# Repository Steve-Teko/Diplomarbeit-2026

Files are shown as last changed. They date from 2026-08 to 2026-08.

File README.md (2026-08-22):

# Diplomarbeit-2026
Offizielle Repository fuer die Diplomarbeit von Steve

**Idee:**
Die Idee ist es Leiterplatten zu designen, die in einem neuen oder bestehenden SmartHome mit einfachen Schritten integrierbar sind.
Es sollen einfache aber Funktionsreiche Leiterplatten die z.B. im Fall des Aktor Prints, per I2C an bereits vorhandene Steuerungen verwendet werden koennen.

**Meine Qualifikationen:**
Gelernt habe ich Automatiker und interessiere mich seit meiner Kindheit fuer viele Technik relevante Themen. Schulisch war ich schon immer einer dem die Themen Kunst und Sprachen weniger interessierten im vergleich zu Mathe, Physik und Handarbeit.
Mit 23 hatte ich eine Entscheidung getroffen, mich Schulisch weiterzubilden. Dies ist bis jetzt immer noch eine Entscheidung die ich nicht bereue. Der Weg bis zu dieser Arbeit war steinig und hart.
Leiterplatten hatte ich einmal in der Lehre mit meinem damaligen Lehrlingsbetreuer gezeichnet, dies aber danach nie mehr ausgefuehrt. Damals hatten wir Eagle als Programm.

**Die Umsetzung:**
Zu diesem Repo existiert noch meine Arbeit die ich Paralell dazu Schreibe. Die Idee des Repo ist es die notwendigen Daten: KiCad, Gerber Files, Gehause oder Programmzeilen fuer spaetere vorhaben zu Speichern.
Die Arbeit werde ich nicht auf das Repo hochladen.

**Haftungsausschluss:**
Ich bin weder fuer die korrekte Anwendung noch meine Fehler Verantwortlich, saemtliche Schaeden die durch alle Dateien auf diesem Repo verursacht wurden, sind alleinig dem Anwender zuzuschreiben.
Die Leiterplatten sind von keinem Pruefunternehmen abgenommen oder auf ihre Sicherheit geprueft worden. Bei Verwendung sind alle Regeln der Technik zu beachten.

#################################################################################################

Official repository for Steve's diploma thesis.

**Idea**
The concept is to design printed circuit boards (PCBs) that can be easily integrated into a new or existing smart home system.
The goal is to create simple yet feature-rich PCBs—such as the actuator board—that can connect to existing control systems via I2C.

**My Qualifications**
I am a trained automation technician (Automatiker) and have been interested in various tech-related topics since childhood. At school, I was always far less interested in art and languages compared to math, physics, and practical crafts.
At age 23, I decided to further my education—a choice I still do not regret. The path leading up to this project has been tough and challenging.
I had designed PCBs once during my apprenticeship alongside my mentor using EAGLE, but I never worked with PCB design again after that.

**Implementation**
In addition to this repository, I am writing my written thesis in parallel. The purpose of this repo is to store the necessary project files—such as KiCad files, Gerber files, enclosure models, or code lines—for future reference.
I will not be uploading the written thesis itself to this repository.

**Disclaimer**
I am responsible neither for the correct application of these files nor for any errors within them. Any damages caused by files in this repository are solely the responsibility of the user.
The PCBs have not been certified or safety-tested by any official inspection body. When using them, all applicable engineering standards and safety codes must be strictly followed.

**What to expect:**
You will be able to order a the Following PCB from your favorite PCB Manufacturer, the Files and a basic Enclosure designed in FreeCAD is included in the Folders

**Hauptprint aka the Brain**
It's purpose is being able to be integrated in to your existing SmartHome while offering a wide range off preconfigured In/Output.
The ESP32 C6 Wroom1 supports Thread/Zigbee, Wi-Fi 6 (2.4gHz only!), Bluetooth 5.0, UART, I2C and I2S.

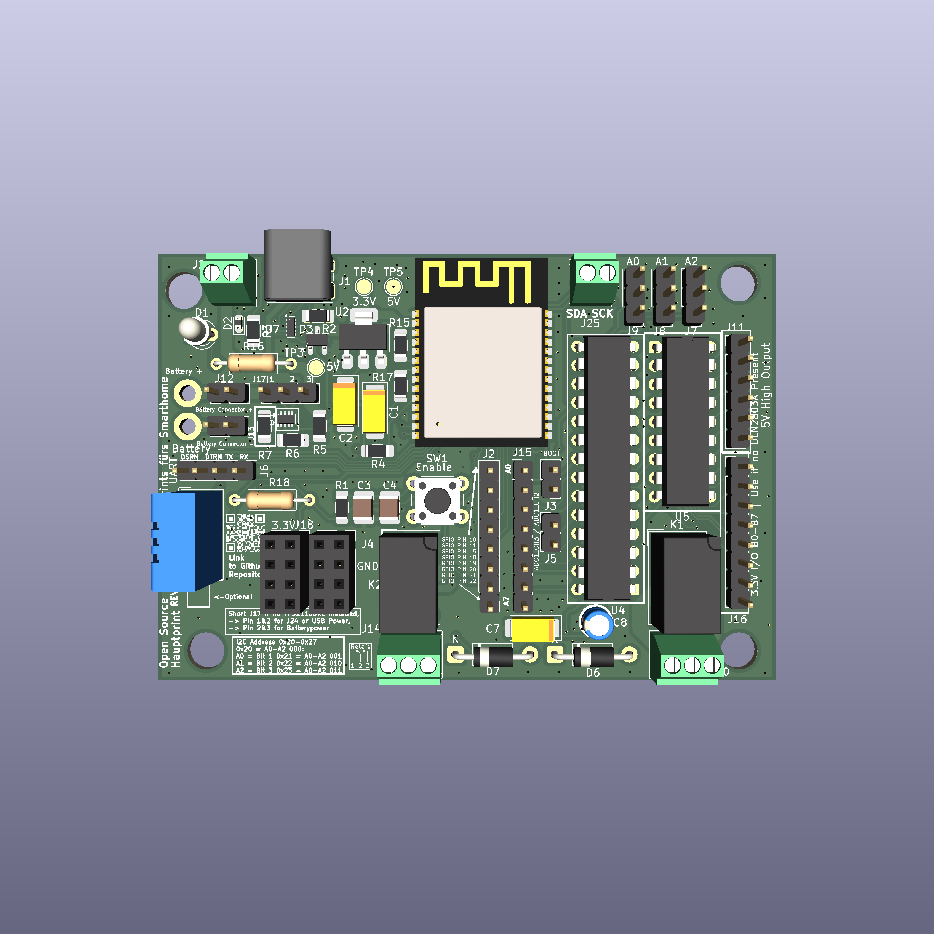
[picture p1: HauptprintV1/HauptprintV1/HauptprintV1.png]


**The RelaisExpanderPrint aka the Switchmaster**
The RelaisExpanderPrint was designed with compatibility and versatility in mind. The Idea was to create a 16x Relays Switching device with Potential-free contacts in mind, as you would find on a PLC or in an Switching Cabinet.
Its size is as compact as i was able to design it with an Power-supply input that support different Voltage Levels depending on your needs.
The TracoPower Component (PS1) is interchangeable in its product line so you can choose Supply Voltages ranging from 9V,12V,24V or up to 75V DC. 

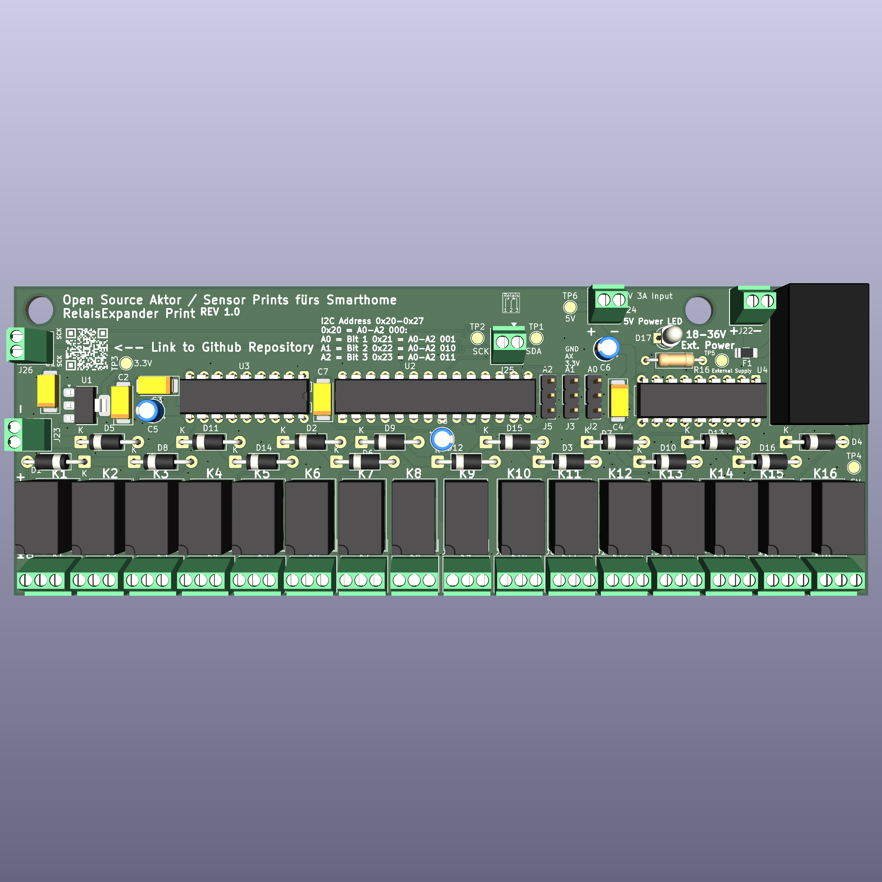
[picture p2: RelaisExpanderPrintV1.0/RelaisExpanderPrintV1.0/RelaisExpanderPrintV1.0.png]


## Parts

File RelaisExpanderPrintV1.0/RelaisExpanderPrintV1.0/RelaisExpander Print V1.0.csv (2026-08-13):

# | Reference | Qty | Value | Footprint | DNP
1 | C1, C5, C6, C8 | 4 | 10uF | Capacitor_Tantalum_SMD:CP_EIA-6032-20_AVX-F_HandSolder
2 | C2 | 1 | 22uF | Capacitor_Tantalum_SMD:CP_EIA-6032-20_AVX-F_HandSolder
3 | C3, C4, C7 | 3 | 100nF | Capacitor_Tantalum_SMD:CP_EIA-6032-20_AVX-F_HandSolder
4 | D1, D2, D3, D4, D5, D6, D7, D8, D9, D10, D11, D12, D13, D14, D15, D16 | 16 | 1N4007 | Diode_THT:D_DO-41_SOD81_P10.16mm_Horizontal
5 | D17 | 1 | LED | LED_THT:LED_D3.0mm_Clear
6 | F1 | 1 | Fuse | Fuse:Fuse_1206_3216Metric
7 | J2 | 1 | A0 | Connector_PinHeader_2.54mm:PinHeader_1x03_P2.54mm_Vertical
8 | J3 | 1 | A1 | Connector_PinHeader_2.54mm:PinHeader_1x03_P2.54mm_Vertical
9 | J4 | 1 | I2C | Connector_PinHeader_2.54mm:PinHeader_1x02_P2.54mm_Vertical
10 | J5 | 1 | A2 | Connector_PinHeader_2.54mm:PinHeader_1x03_P2.54mm_Vertical
11 | J6, J7, J8, J9, J10, J11, J12, J13, J14, J15, J16, J17, J18, J19, J20, J21 | 16 | Screw_Terminal_01x03 | TerminalBlock_Phoenix:TerminalBlock_Phoenix_MPT-0,5-3-2.54_1x03_P2.54mm_Horizontal
12 | J22 | 1 | 18-36V External Powersupply | TerminalBlock_Phoenix:TerminalBlock_Phoenix_MPT-0,5-2-2.54_1x02_P2.54mm_Horizontal
13 | J23 | 1 | 5V Out | TerminalBlock_Phoenix:TerminalBlock_Phoenix_MPT-0,5-2-2.54_1x02_P2.54mm_Horizontal
14 | K1, K2, K3, K4, K5, K6, K7, K8, K9, K10, K11, K12, K13, K14, K15, K16 | 16 | G5LE-1 | Relay_THT:Relay_SPDT_Omron_G5V-1
15 | PS1 | 1 | TEL_15-2411N | Converter_DCDC:Converter_DCDC_TRACO_TEL12-xxxx_THT
16 | R16 | 1 | 300 | Resistor_THT:R_Axial_DIN0207_L6.3mm_D2.5mm_P10.16mm_Horizontal
17 | U1 | 1 | AMS1117-3.3 | Package_TO_SOT_SMD:SOT-223-3_TabPin2
18 | U2 | 1 | MCP23017_SP | Package_DIP:DIP-28_W7.62mm
19 | U3, U4 | 2 | ULN2803A | Package_DIP:DIP-18_W7.62mm

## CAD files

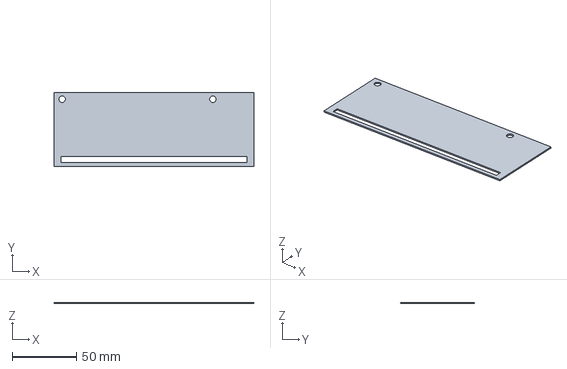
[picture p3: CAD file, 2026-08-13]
RelaisExpanderPrintV1.0/RelaisExpanderPrintV1.0/Gehause_Deckel.3mf
156.0 x 58.0 x 1.00 mm

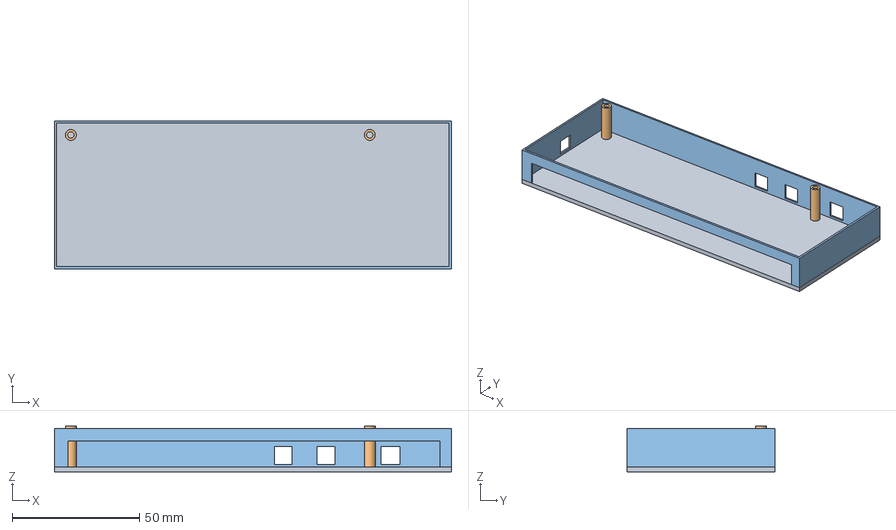
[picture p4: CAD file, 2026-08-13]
RelaisExpanderPrintV1.0/RelaisExpanderPrintV1.0/Gehause.FCStd
156.0 x 58.0 x 18.0 mm
Bottom
Loecher001

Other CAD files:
RelaisExpanderPrintV1.0/RelaisExpanderPrintV1.0/Gehause_boden.3mf

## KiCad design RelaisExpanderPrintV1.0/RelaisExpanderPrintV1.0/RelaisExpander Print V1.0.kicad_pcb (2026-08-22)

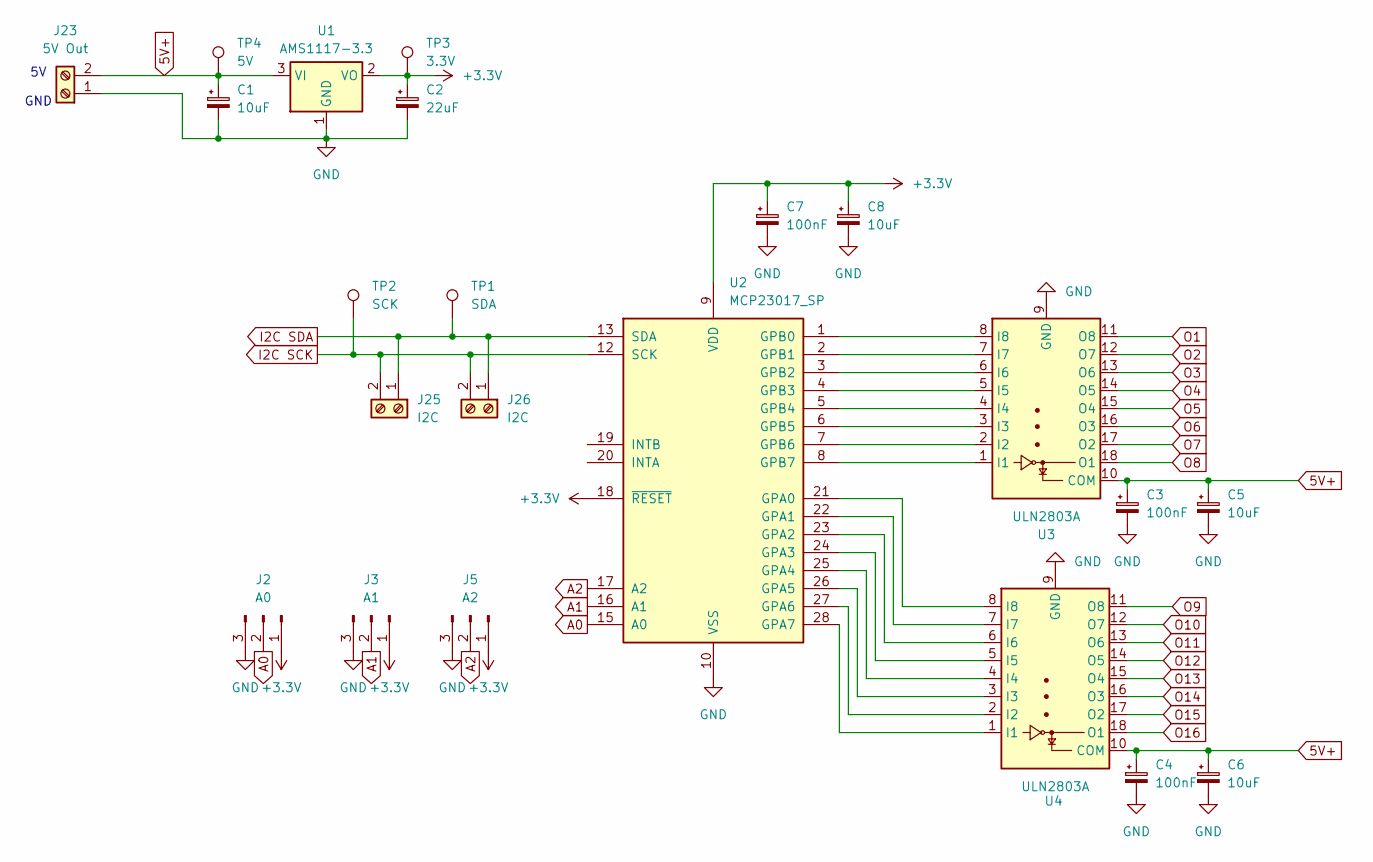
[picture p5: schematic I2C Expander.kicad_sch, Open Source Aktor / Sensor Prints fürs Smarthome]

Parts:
C1: 10uF; CP_EIA-6032-20_AVX-F_HandSolder
C2: 22uF; CP_EIA-6032-20_AVX-F_HandSolder
C3, C4, C7: 100nF; CP_EIA-6032-20_AVX-F_HandSolder
C5, C6, C8: 10uF; CP_Radial_D4.0mm_P1.50mm
J2: A0; PinHeader_1x03_P2.54mm_Vertical
J3: A1; PinHeader_1x03_P2.54mm_Vertical
J5: A2; PinHeader_1x03_P2.54mm_Vertical
J23: 5V Out; TerminalBlock_Phoenix_MPT-0,5-2-2.54_1x02_P2.54mm_Horizontal
J25, J26: I2C; TerminalBlock_Phoenix_MPT-0,5-2-2.54_1x02_P2.54mm_Horizontal
TP1: SDA; TestPoint_Pad_D2.0mm
TP2: SCK; TestPoint_Pad_D2.0mm
TP3: 3.3V; TestPoint_Pad_D2.0mm
TP4: 5V; TestPoint_Pad_D2.0mm
U1: AMS1117-3.3; SOT-223-3_TabPin2
U2: MCP23017_SP; DIP-28_W7.62mm
U3, U4: ULN2803A; DIP-18_W7.62mm

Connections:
5V+: C1.1, C3.1, C4.1, C5.1, C6.1, J23.2, TP4.1 (1_1), U1.3 (VI), U3.10 (COM), U4.10 (COM); also elsewhere on the board
+3.3V: C2.1, C7.1, C8.1, J2.1, J3.1, J5.1, TP3.1 (1_1), U1.2 (VO), U2.9 (VDD), U2.18 (~RESET)
A0: J2.2, U2.15 (A0)
A1: J3.2, U2.16 (A1)
A2: J5.2, U2.17 (A2)
GND: C1.2, C2.2, C3.2, C4.2, C5.2, C6.2, C7.2, C8.2, J2.3, J3.3, J5.3, J23.1, U1.1 (GND), U2.10 (VSS), U3.9 (GND), U4.9 (GND); also elsewhere on the board
I2C SCK: J25.2, J26.2, TP2.1 (1_1), U2.12 (SCK)
I2C SDA: J25.1, J26.1, TP1.1 (1_1), U2.13 (SDA)
unnamed: U2.21 (GPA0), U4.8 (I8)
unnamed: U2.22 (GPA1), U4.7 (I7)
unnamed: U2.23 (GPA2), U4.6 (I6)
unnamed: U2.24 (GPA3), U4.5 (I5)
unnamed: U2.25 (GPA4), U4.4 (I4)
unnamed: U2.26 (GPA5), U4.3 (I3)
unnamed: U2.27 (GPA6), U4.2 (I2)
unnamed: U2.28 (GPA7), U4.1 (I1)
unnamed: U2.1 (GPB0), U3.8 (I8)
unnamed: U2.2 (GPB1), U3.7 (I7)
unnamed: U2.3 (GPB2), U3.6 (I6)
unnamed: U2.4 (GPB3), U3.5 (I5)
unnamed: U2.5 (GPB4), U3.4 (I4)
unnamed: U2.6 (GPB5), U3.3 (I3)
unnamed: U2.7 (GPB6), U3.2 (I2)
unnamed: U2.8 (GPB7), U3.1 (I1)
O1: U3.11 (O8); also elsewhere on the board
O2: U3.12 (O7); also elsewhere on the board
O3: U3.13 (O6); also elsewhere on the board
O4: U3.14 (O5); also elsewhere on the board
O5: U3.15 (O4); also elsewhere on the board
O6: U3.16 (O3); also elsewhere on the board
O7: U3.17 (O2); also elsewhere on the board
O8: U3.18 (O1); also elsewhere on the board
O9: U4.11 (O8); also elsewhere on the board
O10: U4.12 (O7); also elsewhere on the board
O11: U4.13 (O6); also elsewhere on the board
O12: U4.14 (O5); also elsewhere on the board
O13: U4.15 (O4); also elsewhere on the board
O14: U4.16 (O3); also elsewhere on the board
O15: U4.17 (O2); also elsewhere on the board
O16: U4.18 (O1); also elsewhere on the board

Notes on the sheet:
5V GND

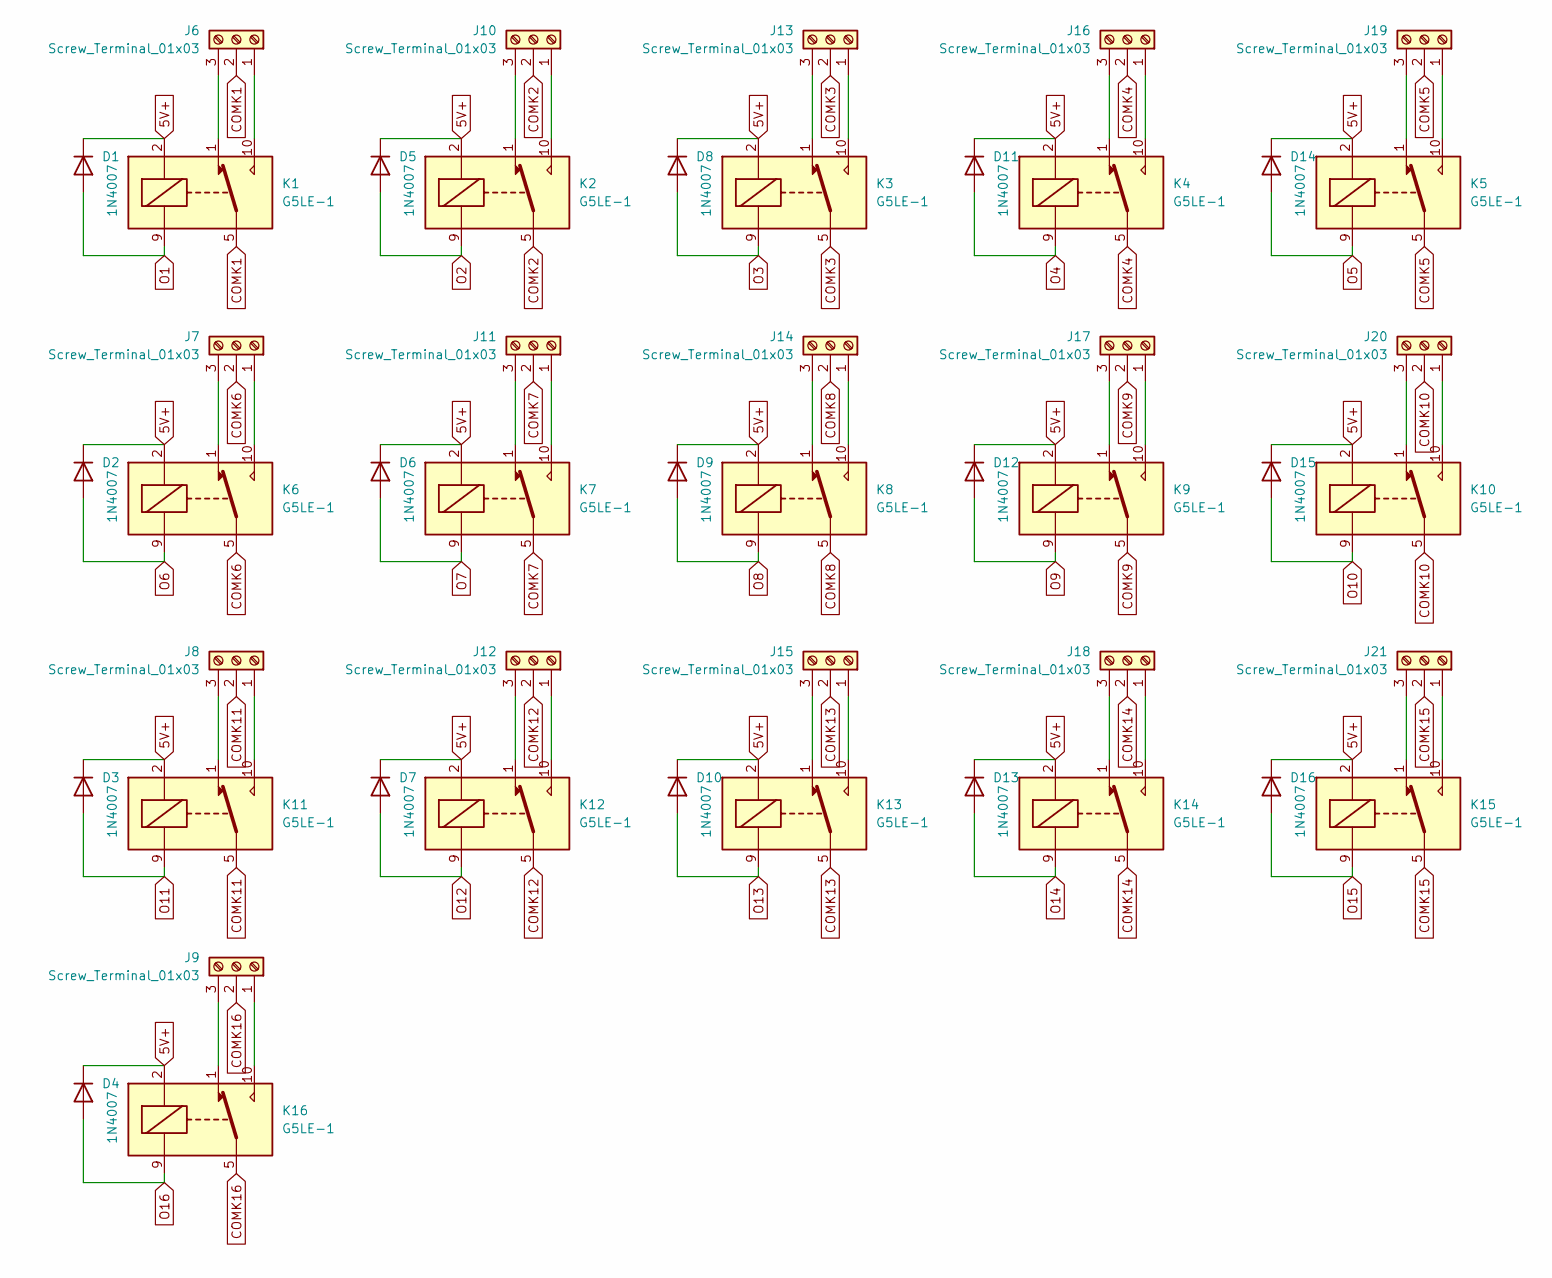
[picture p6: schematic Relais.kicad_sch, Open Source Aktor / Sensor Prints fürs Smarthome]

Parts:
D1, D2, D3, D4, D5, D6, D7, D8, D9, D10, D11, D12, D13, D14, D15, D16: 1N4007; D_DO-41_SOD81_P10.16mm_Horizontal
J6, J7, J8, J9, J10, J11, J12, J13, J14, J15, J16, J17, J18, J19, J20, J21: Screw_Terminal_01x03; TerminalBlock_Phoenix_MPT-0,5-3-2.54_1x03_P2.54mm_Horizontal
K1, K2, K3, K4, K5, K6, K7, K8, K9, K10, K11, K12, K13, K14, K15, K16: G5LE-1; Relay_SPDT_Omron_G5V-1

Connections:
5V+: D1.1 (K), D2.1 (K), D3.1 (K), D4.1 (K), D5.1 (K), D6.1 (K), D7.1 (K), D8.1 (K), D9.1 (K), D10.1 (K), D11.1 (K), D12.1 (K), D13.1 (K), D14.1 (K), D15.1 (K), D16.1 (K), K1.2, K2.2, K3.2, K4.2, K5.2, K6.2, K7.2, K8.2, K9.2, K10.2, K11.2, K12.2, K13.2, K14.2, K15.2, K16.2; also elsewhere on the board
COMK1: J6.2, K1.5, K1.6
COMK2: J10.2, K2.5, K2.6
COMK3: J13.2, K3.5, K3.6
COMK4: J16.2, K4.5, K4.6
COMK5: J19.2, K5.5, K5.6
COMK6: J7.2, K6.5, K6.6
COMK7: J11.2, K7.5, K7.6
COMK8: J14.2, K8.5, K8.6
COMK9: J17.2, K9.5, K9.6
COMK10: J20.2, K10.5, K10.6
COMK11: J8.2, K11.5, K11.6
COMK12: J12.2, K12.5, K12.6
COMK13: J15.2, K13.5, K13.6
COMK14: J18.2, K14.5, K14.6
COMK15: J21.2, K15.5, K15.6
COMK16: J9.2, K16.5, K16.6
unnamed: J6.1, K1.10
unnamed: J6.3, K1.1
unnamed: J7.1, K6.10
unnamed: J7.3, K6.1
unnamed: J8.1, K11.10
unnamed: J8.3, K11.1
unnamed: J9.1, K16.10
unnamed: J9.3, K16.1
unnamed: J10.1, K2.10
unnamed: J10.3, K2.1
unnamed: J11.1, K7.10
unnamed: J11.3, K7.1
unnamed: J12.1, K12.10
unnamed: J12.3, K12.1
unnamed: J13.1, K3.10
unnamed: J13.3, K3.1
unnamed: J14.1, K8.10
unnamed: J14.3, K8.1
unnamed: J15.1, K13.10
unnamed: J15.3, K13.1
unnamed: J16.1, K4.10
unnamed: J16.3, K4.1
unnamed: J17.1, K9.10
unnamed: J17.3, K9.1
unnamed: J18.1, K14.10
unnamed: J18.3, K14.1
unnamed: J19.1, K5.10
unnamed: J19.3, K5.1
unnamed: J20.1, K10.10
unnamed: J20.3, K10.1
unnamed: J21.1, K15.10
unnamed: J21.3, K15.1
O1: D1.2 (A), K1.9; also elsewhere on the board
O2: D5.2 (A), K2.9; also elsewhere on the board
O3: D8.2 (A), K3.9; also elsewhere on the board
O4: D11.2 (A), K4.9; also elsewhere on the board
O5: D14.2 (A), K5.9; also elsewhere on the board
O6: D2.2 (A), K6.9; also elsewhere on the board
O7: D6.2 (A), K7.9; also elsewhere on the board
O8: D9.2 (A), K8.9; also elsewhere on the board
O9: D12.2 (A), K9.9; also elsewhere on the board
O10: D15.2 (A), K10.9; also elsewhere on the board
O11: D3.2 (A), K11.9; also elsewhere on the board
O12: D7.2 (A), K12.9; also elsewhere on the board
O13: D10.2 (A), K13.9; also elsewhere on the board
O14: D13.2 (A), K14.9; also elsewhere on the board
O15: D16.2 (A), K15.9; also elsewhere on the board
O16: D4.2 (A), K16.9; also elsewhere on the board

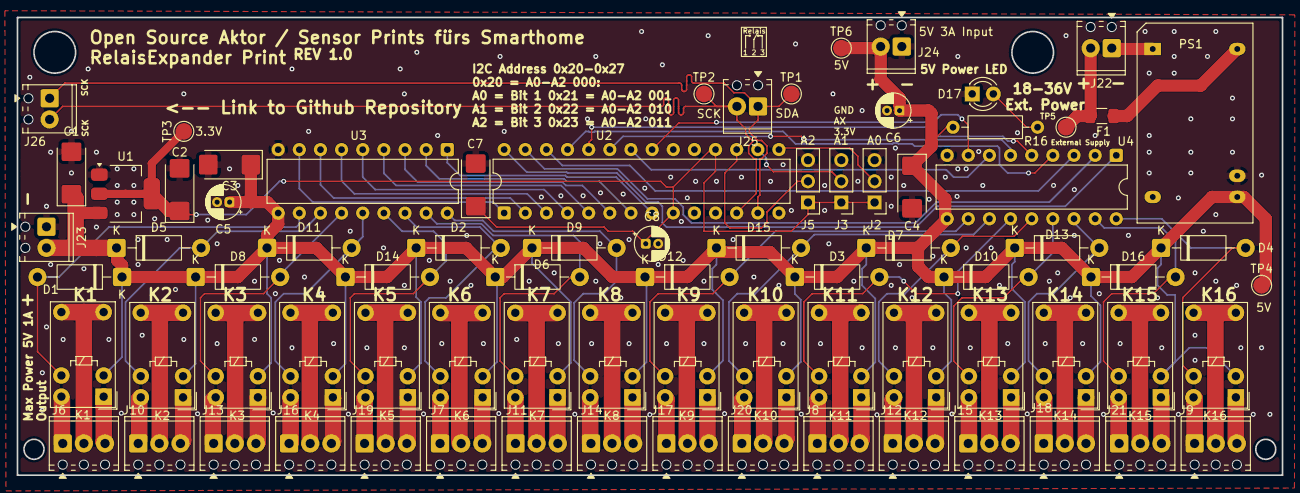
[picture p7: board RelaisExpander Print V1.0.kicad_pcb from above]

Board: 2 copper layers, 152.0 x 55.0 mm, 78 parts (0 on the bottom side), 92 nets.

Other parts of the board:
D17: LED; LED_D3.0mm_Clear
F1: Fuse; Fuse_1206_3216Metric
J22: 18-36V External Powersupply; TerminalBlock_Phoenix_MPT-0,5-2-2.54_1x02_P2.54mm_Horizontal
J24: 5V 3A Input; TerminalBlock_Phoenix_MPT-0,5-2-2.54_1x02_P2.54mm_Horizontal
PS1: TEL_15-2411N; Converter_DCDC_TRACO_TEL12-xxxx_THT
R16: 300; R_Axial_DIN0207_L6.3mm_D2.5mm_P10.16mm_Horizontal
TP5: External Supply; TestPoint_Pad_D2.0mm
TP6: 5V; TestPoint_Pad_D2.0mm

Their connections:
5V+: J24.2, PS1.9 (+VOUT), R16.2, TP6.1 (1_1); also elsewhere on the board
GND: D17.1 (K), J24.1, PS1.10 (-VOUT); also elsewhere on the board
unnamed: D17.2 (A), R16.1
unnamed: J22.1, PS1.1 (-VIN)
unnamed: F1.1, J22.2, TP5.1 (1_1)
unnamed: F1.2, PS1.16 (+VIN)

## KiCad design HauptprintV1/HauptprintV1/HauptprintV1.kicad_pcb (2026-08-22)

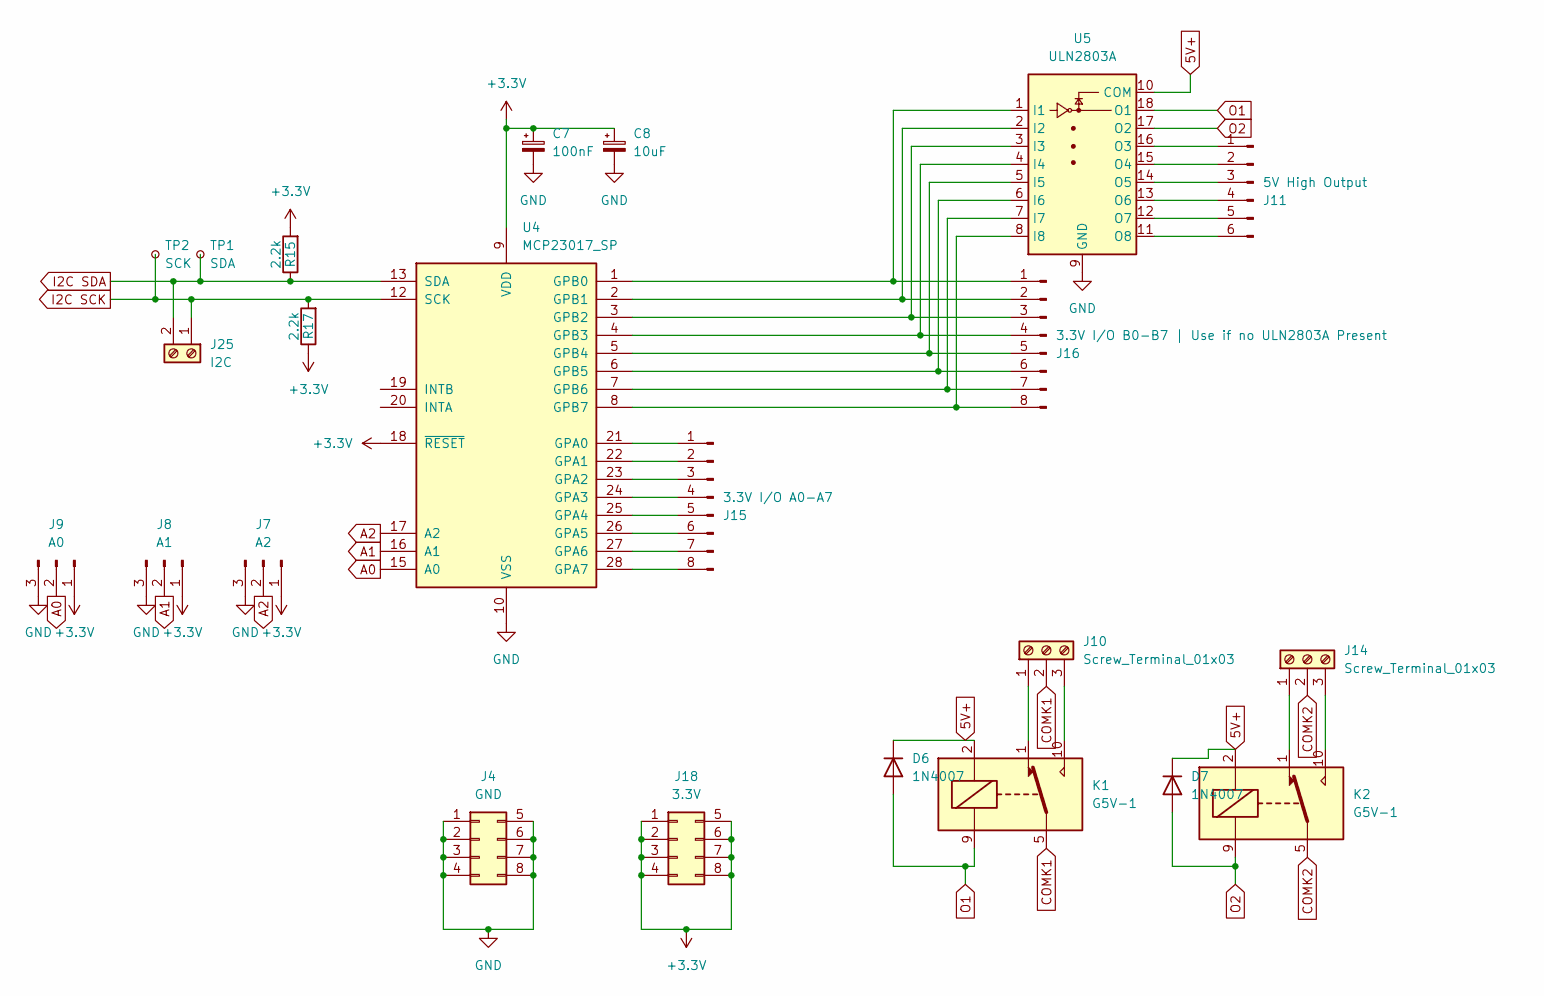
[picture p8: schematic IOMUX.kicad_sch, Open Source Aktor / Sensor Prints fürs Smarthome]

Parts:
C7: 100nF; CP_EIA-6032-20_AVX-F_HandSolder
C8: 10uF; CP_Radial_D4.0mm_P1.50mm
D6, D7: 1N4007; D_DO-41_SOD81_P10.16mm_Horizontal
J4: GND; PinSocket_2x04_P2.54mm_Vertical
J7: A2; PinHeader_1x03_P2.54mm_Vertical
J8: A1; PinHeader_1x03_P2.54mm_Vertical
J9: A0; PinHeader_1x03_P2.54mm_Vertical
J10, J14: Screw_Terminal_01x03; TerminalBlock_Phoenix_MPT-0,5-3-2.54_1x03_P2.54mm_Horizontal
J11: 5V High Output; PinHeader_1x06_P2.54mm_Vertical
J15: 3.3V I/O A0-A7; PinHeader_1x08_P2.54mm_Vertical
J16: 3.3V I/O B0-B7 | Use if no ULN2803A Present; PinHeader_1x08_P2.54mm_Vertical
J18: 3.3V; PinSocket_2x04_P2.54mm_Vertical
J25: I2C; TerminalBlock_Phoenix_MPT-0,5-2-2.54_1x02_P2.54mm_Horizontal
K1, K2: G5V-1; Relay_SPDT_Omron_G5V-1
R15, R17: 2.2k; R_1206_3216Metric_Pad1.30x1.75mm_HandSolder
TP1: SDA; TestPoint_Pad_D2.0mm
TP2: SCK; TestPoint_Pad_D2.0mm
U4: MCP23017_SP; DIP-28_W7.62mm
U5: ULN2803A; DIP-18_W7.62mm

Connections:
3.3V: C7.1, C8.1, J7.1, J8.1, J9.1, J18.1, J18.2, J18.3, J18.4, J18.5, J18.6, J18.7, J18.8, R15.2, R17.1, U4.9 (VDD), U4.18 (~RESET); also elsewhere on the board
5V+: D6.1 (K), D7.1 (K), K1.2, K2.2, U5.10 (COM); also elsewhere on the board
A0: J9.2, U4.15 (A0)
A1: J8.2, U4.16 (A1)
A2: J7.2, U4.17 (A2)
COMK1: J10.2, K1.5, K1.6
COMK2: J14.2, K2.5, K2.6
GND: C7.2, C8.2, J4.1, J4.2, J4.3, J4.4, J4.5, J4.6, J4.7, J4.8, J7.3, J8.3, J9.3, U4.10 (VSS), U5.9 (GND); also elsewhere on the board
I2C SCK: J25.1, R17.2, TP2.1 (1_1), U4.12 (SCK); also elsewhere on the board
I2C SDA: J25.2, R15.1, TP1.1 (1_1), U4.13 (SDA); also elsewhere on the board
unnamed: J10.1, K1.1
unnamed: J10.3, K1.10
unnamed: J11.1, U5.16 (O3)
unnamed: J11.2, U5.15 (O4)
unnamed: J11.3, U5.14 (O5)
unnamed: J11.4, U5.13 (O6)
unnamed: J11.5, U5.12 (O7)
unnamed: J11.6, U5.11 (O8)
unnamed: J14.1, K2.1
unnamed: J14.3, K2.10
unnamed: J15.1, U4.21 (GPA0)
unnamed: J15.2, U4.22 (GPA1)
unnamed: J15.3, U4.23 (GPA2)
unnamed: J15.4, U4.24 (GPA3)
unnamed: J15.5, U4.25 (GPA4)
unnamed: J15.6, U4.26 (GPA5)
unnamed: J15.7, U4.27 (GPA6)
unnamed: J15.8, U4.28 (GPA7)
unnamed: J16.1, U4.1 (GPB0), U5.1 (I1)
unnamed: J16.2, U4.2 (GPB1), U5.2 (I2)
unnamed: J16.3, U4.3 (GPB2), U5.3 (I3)
unnamed: J16.4, U4.4 (GPB3), U5.4 (I4)
unnamed: J16.5, U4.5 (GPB4), U5.5 (I5)
unnamed: J16.6, U4.6 (GPB5), U5.6 (I6)
unnamed: J16.7, U4.7 (GPB6), U5.7 (I7)
unnamed: J16.8, U4.8 (GPB7), U5.8 (I8)
O1: D6.2 (A), K1.9, U5.18 (O1)
O2: D7.2 (A), K2.9, U5.17 (O2)

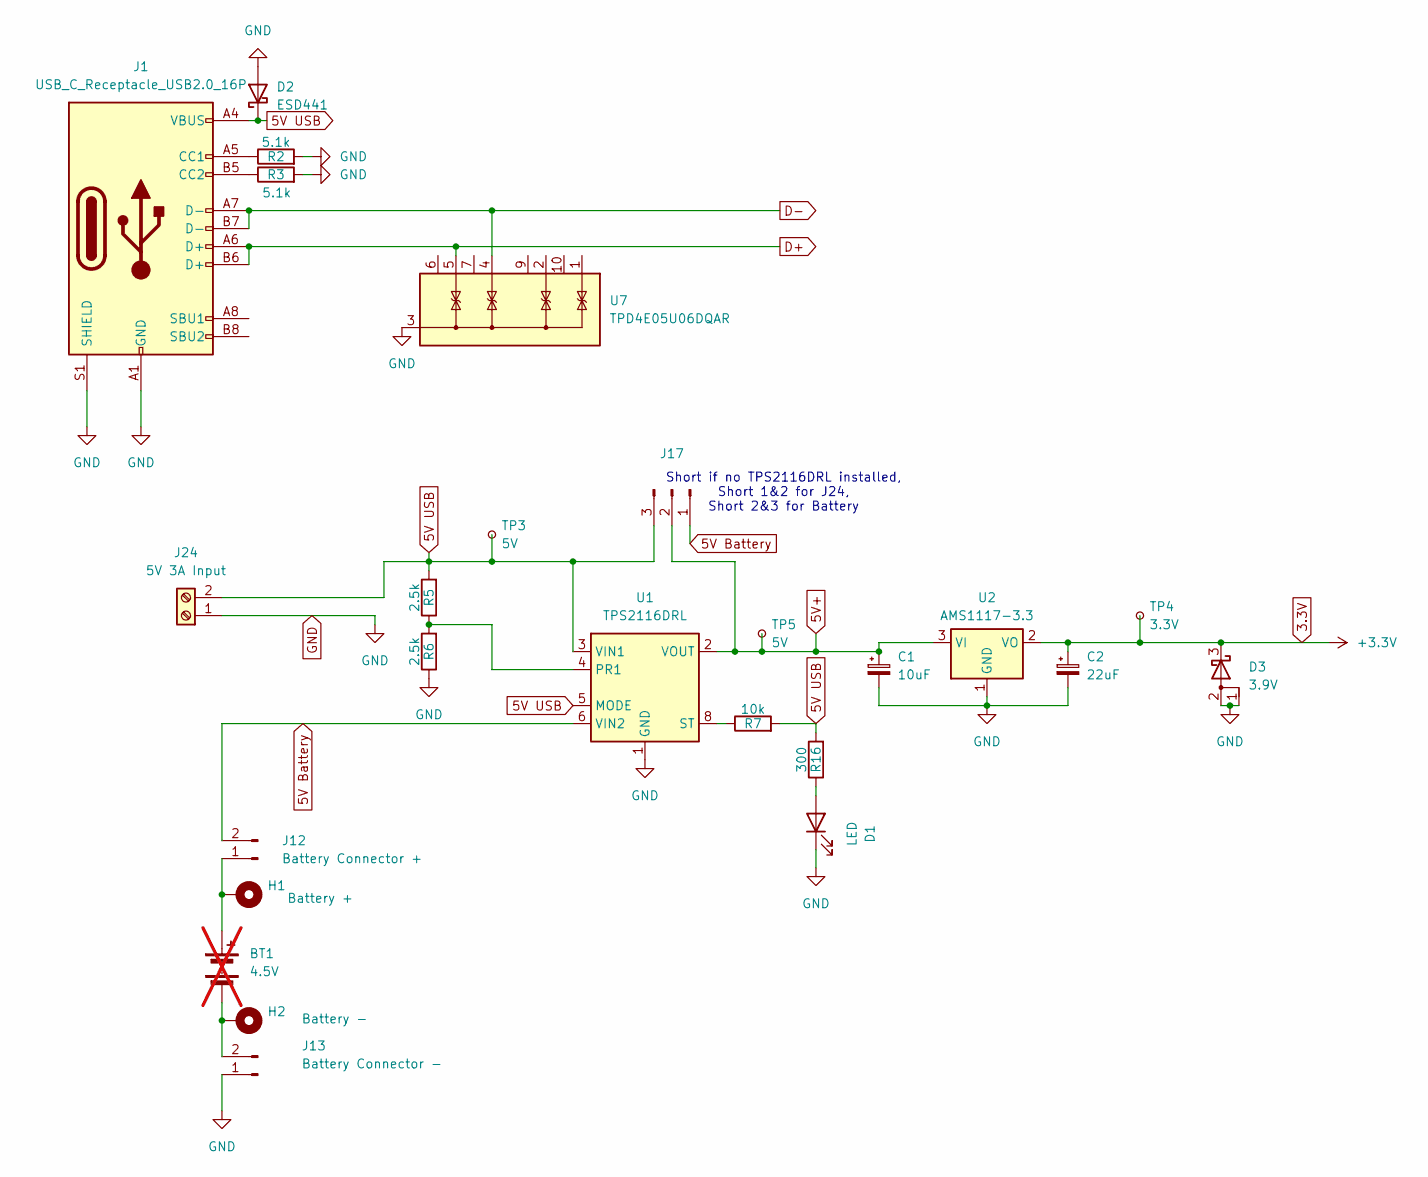
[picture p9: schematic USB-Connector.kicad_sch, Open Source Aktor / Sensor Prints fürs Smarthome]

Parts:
BT1: 4.5V; not fitted
C1: 10uF; CP_EIA-6032-20_AVX-F_HandSolder
C2: 22uF; CP_EIA-6032-20_AVX-F_HandSolder
D1: LED; LED_D3.0mm_Clear
D2: ESD441; D_0603_1608Metric
D3: 3.9V; TSOT-23
H1: Battery +; MountingHole_2.2mm_M2_DIN965_Pad
H2: Battery -; MountingHole_2.2mm_M2_DIN965_Pad
J1: USB_C_Receptacle_USB2.0_16P; USB_C_Receptacle_GCT_USB4085
J12: Battery Connector +; PinHeader_1x02_P2.54mm_Vertical
J13: Battery Connector -; PinHeader_1x02_P2.54mm_Vertical
J17: PinHeader_1x03_P2.54mm_Vertical
J24: 5V 3A Input; TerminalBlock_Phoenix_MPT-0,5-2-2.54_1x02_P2.54mm_Horizontal
R2, R3: 5.1k; R_1206_3216Metric_Pad1.30x1.75mm_HandSolder
R5, R6: 2.5k; R_1206_3216Metric_Pad1.30x1.75mm_HandSolder
R7: 10k; R_1206_3216Metric_Pad1.30x1.75mm_HandSolder
R16: 300; R_Axial_DIN0207_L6.3mm_D2.5mm_P10.16mm_Horizontal
TP3, TP5: 5V; TestPoint_Pad_D2.0mm
TP4: 3.3V; TestPoint_Pad_D2.0mm
U1: TPS2116DRL; SOT-583-8
U2: AMS1117-3.3; SOT-223-3_TabPin2
U7: TPD4E05U06DQAR; USON-10_2.5x1.0mm_P0.5mm

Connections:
3.3V: C2.1, D3.3 (K), TP4.1 (1_1), U2.2 (VO); also elsewhere on the board
5V Battery: J12.2, J17.1, U1.6 (VIN2)
5V USB: D2.1 (K), J1.A4 (VBUS), J1.A9 (VBUS), J1.B4 (VBUS), J1.B9 (VBUS), J17.3, J24.2, R5.2, R7.2, R16.2, TP3.1 (1_1), U1.3 (VIN1), U1.5 (MODE)
5V+: C1.1, J17.2, TP5.1 (1_1), U1.2 (VOUT), U1.7 (VOUT), U2.3 (VI); also elsewhere on the board
D+: J1.A6 (D+), J1.B6 (D+), U7.5 (IO4); also elsewhere on the board
D-: J1.A7 (D-), J1.B7 (D-), U7.4 (IO3); also elsewhere on the board
GND: C1.2, C2.2, D1.1 (K), D2.2 (A), D3.1 (A), D3.2 (A), J1.A1 (GND), J1.A12 (GND), J1.B1 (GND), J1.B12 (GND), J1.S1 (SHIELD), J13.1, J24.1, R2.2, R3.2, R6.1, U1.1 (GND), U2.1 (GND), U7.3 (G), U7.8 (G); also elsewhere on the board
unnamed: D1.2 (A), R16.1
unnamed: J1.A5 (CC1), R2.1
unnamed: J1.B5 (CC2), R3.1
unnamed: BT1.1 (+), H1.1 (1_1), J12.1
unnamed: BT1.2 (-), H2.1 (1_1), J13.2
unnamed: R5.1, R6.2, U1.4 (PR1)
unnamed: R7.1, U1.8 (ST)

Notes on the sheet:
Short if no TPS2116DRL installed, Short 1&2 for J24, Short 2&3 for Battery

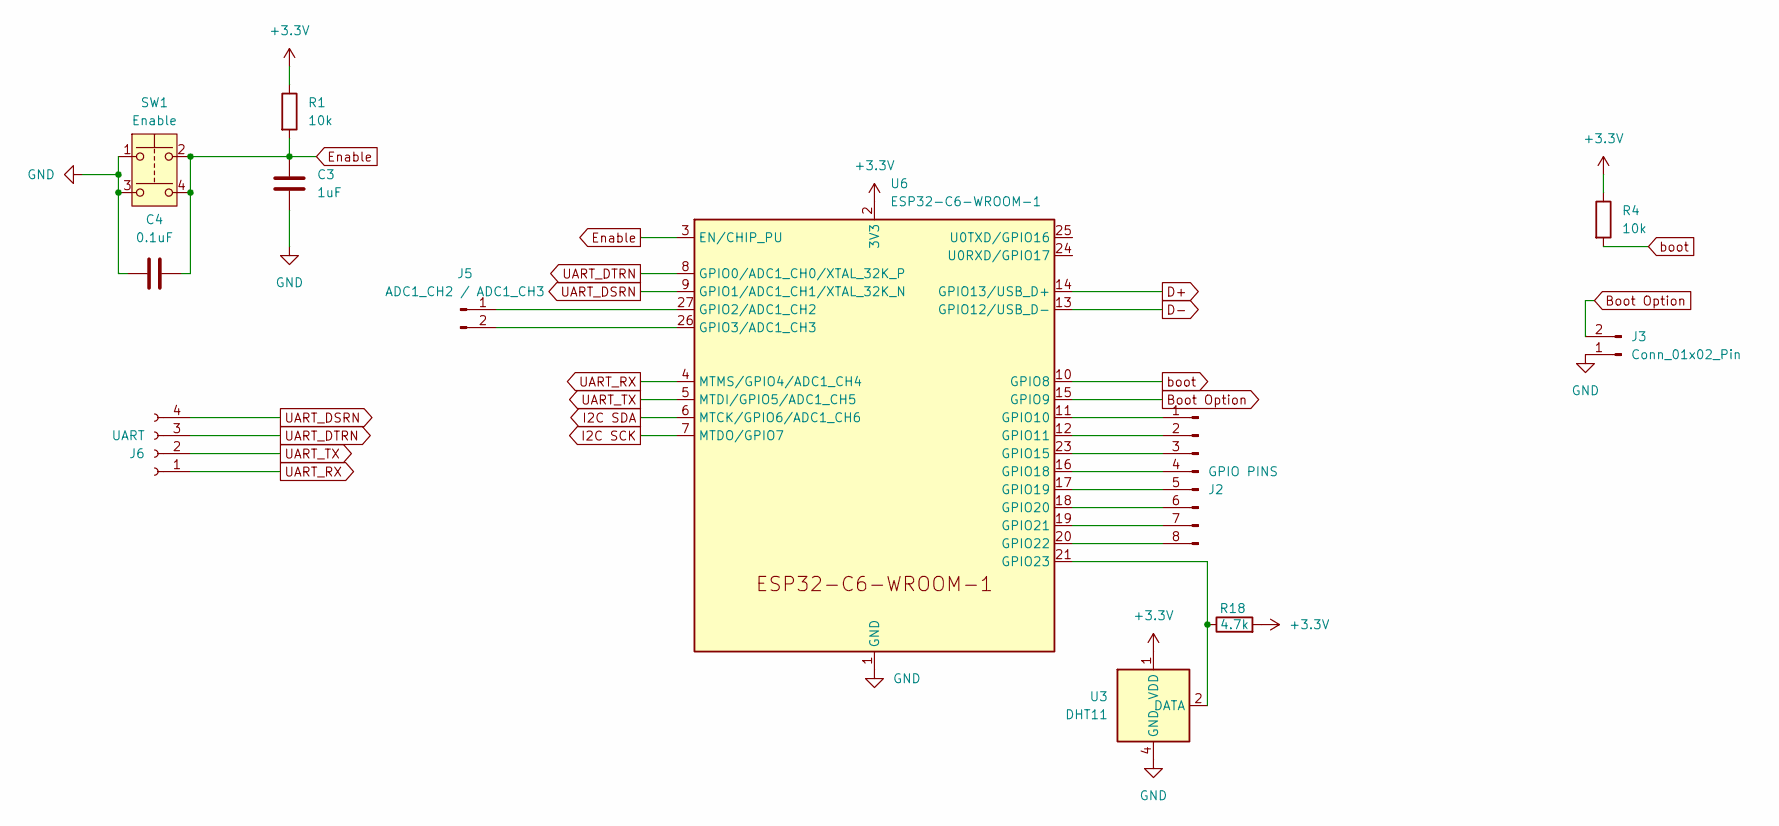
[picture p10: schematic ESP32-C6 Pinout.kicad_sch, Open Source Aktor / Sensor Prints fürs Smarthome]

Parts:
C3: 1uF; C_1210_3225Metric_Pad1.33x2.70mm_HandSolder
C4: 0.1uF; C_1210_3225Metric_Pad1.33x2.70mm_HandSolder
J2: GPIO PINS; PinHeader_1x08_P2.54mm_Vertical
J3: Conn_01x02_Pin; PinHeader_1x02_P2.54mm_Vertical
J5: ADC1_CH2 / ADC1_CH3; PinHeader_1x02_P2.54mm_Vertical
J6: UART; PinHeader_1x04_P2.54mm_Vertical
R1, R4: 10k; R_1206_3216Metric_Pad1.30x1.75mm_HandSolder
R18: 4.7k; R_Axial_DIN0207_L6.3mm_D2.5mm_P10.16mm_Horizontal
SW1: Enable; SW_PUSH_6mm
U3: DHT11; Aosong_DHT11_5.5x12.0_P2.54mm
U6: ESP32-C6-WROOM-1

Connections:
3.3V: R1.1, R4.1, R18.2, U3.1 (VDD), U6.2 (3V3); also elsewhere on the board
Boot Option: J3.2, U6.15 (GPIO9)
D+: U6.14 (GPIO13/USB_D+); also elsewhere on the board
D-: U6.13 (GPIO12/USB_D-); also elsewhere on the board
Enable: C3.1, C4.2, R1.2, SW1.2, SW1.4, U6.3 (EN/CHIP_PU)
GND: C3.2, C4.1, J3.1, SW1.1, SW1.3, U3.4 (GND), U6.1 (GND), U6.28 (GND), U6.29 (GND); also elsewhere on the board
I2C SCK: U6.7 (MTDO/GPIO7); also elsewhere on the board
I2C SDA: U6.6 (MTCK/GPIO6/ADC1_CH6); also elsewhere on the board
unnamed: J2.1, U6.11 (GPIO10)
unnamed: J2.2, U6.12 (GPIO11)
unnamed: J2.3, U6.23 (GPIO15)
unnamed: J2.4, U6.16 (GPIO18)
unnamed: J2.5, U6.17 (GPIO19)
unnamed: J2.6, U6.18 (GPIO20)
unnamed: J2.7, U6.19 (GPIO21)
unnamed: J2.8, U6.20 (GPIO22)
unnamed: J5.1, U6.27 (GPIO2/ADC1_CH2)
unnamed: J5.2, U6.26 (GPIO3/ADC1_CH3)
unnamed: R18.1, U3.2 (DATA), U6.21 (GPIO23)
UART_DSRN: J6.4, U6.9 (GPIO1/ADC1_CH1/XTAL_32K_N)
UART_DTRN: J6.3, U6.8 (GPIO0/ADC1_CH0/XTAL_32K_P)
UART_RX: J6.1, U6.4 (MTMS/GPIO4/ADC1_CH4)
UART_TX: J6.2, U6.5 (MTDI/GPIO5/ADC1_CH5)
boot: R4.2, U6.10 (GPIO8)

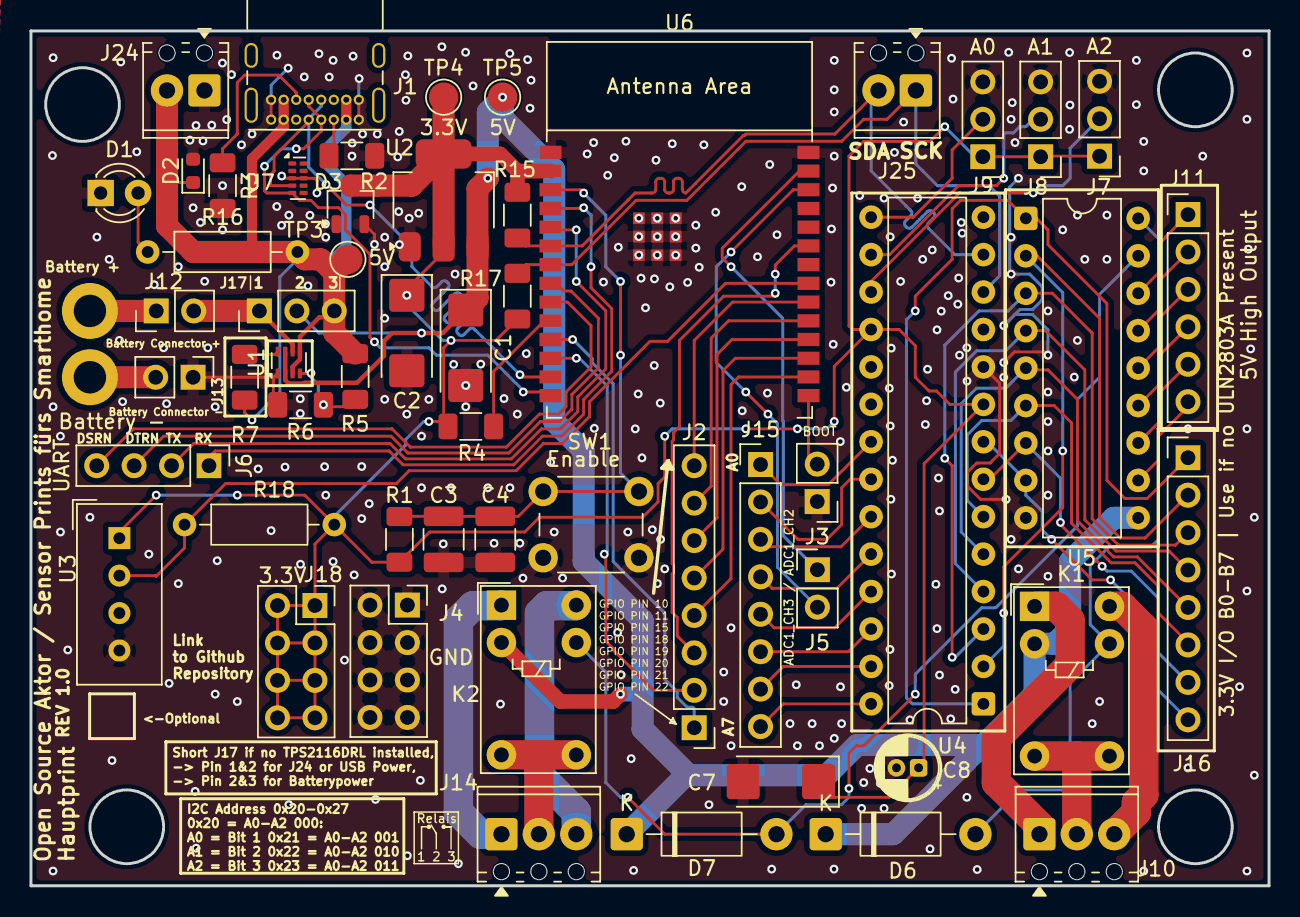
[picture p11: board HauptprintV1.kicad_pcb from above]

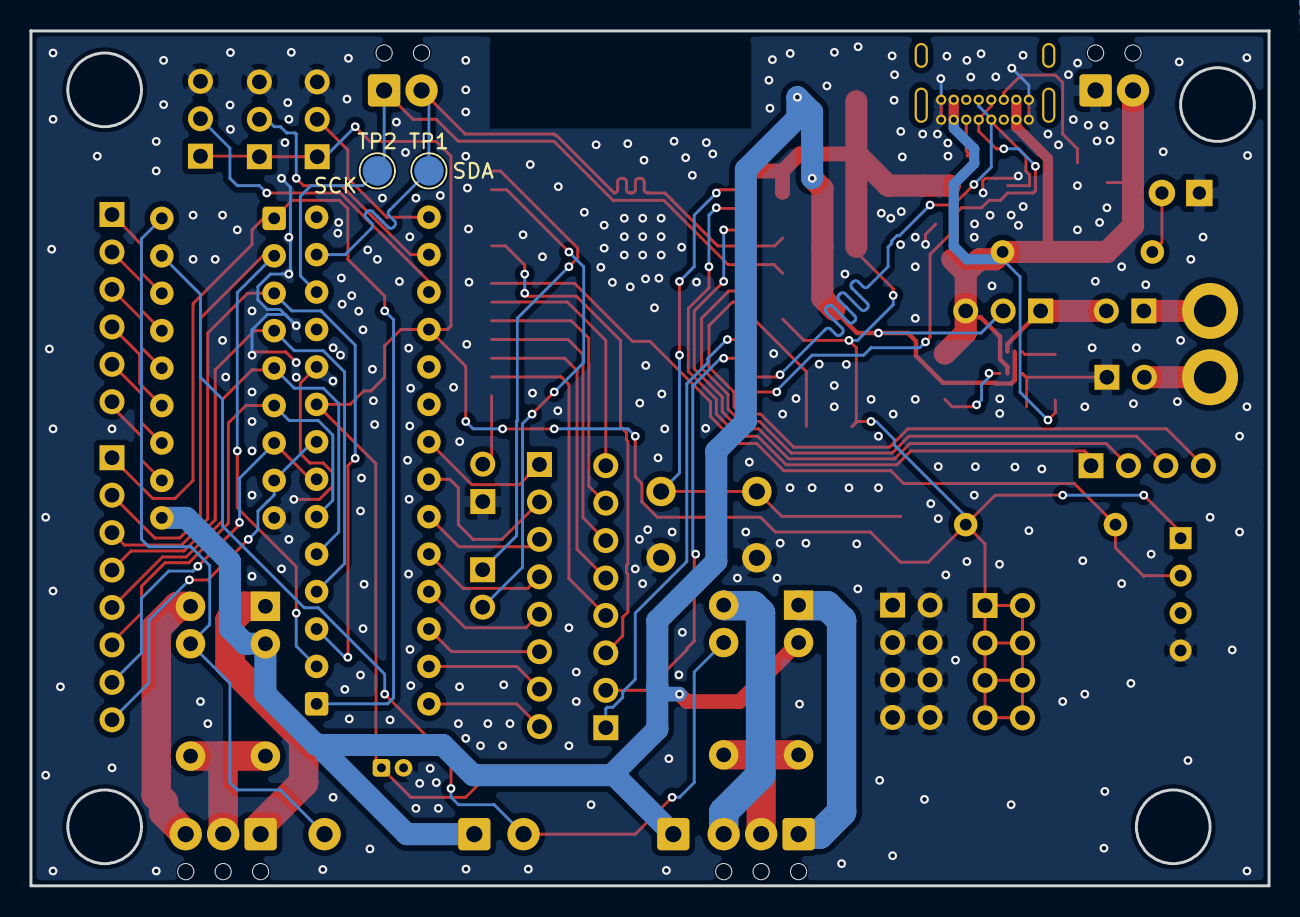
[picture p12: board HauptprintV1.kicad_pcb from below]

Board: 2 copper layers, 84.0 x 58.0 mm, 59 parts (2 on the bottom side), 67 nets.

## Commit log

2026-08-13 Upload V1.0
    Expander Print Final Version
    [RelaisExpander Print V1.0-B_Cu.gbr, RelaisExpander Print V1.0-B_Mask.gbr, RelaisExpander Print V1.0-B_Silkscreen.gbr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]
2026-08-17 Minor Adjustments
    [RelaisExpander Print V1.0.kicad_pcb]
2026-08-22 Upload of Hauptprint
    [RelaisExpander Print V1.0-B_Cu.gbr, RelaisExpander Print V1.0-B_Mask.gbr, RelaisExpander Print V1.0-B_Silkscreen.gbr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]
2026-08-22 deleted some stuff
    [External Power.kicad_sch, Gehause.FCStd, Gehause_Deckel.3mf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]
